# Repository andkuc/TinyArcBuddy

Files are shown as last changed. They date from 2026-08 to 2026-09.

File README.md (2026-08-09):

# Tiny Arc Buddy: Embedded STEM Education Platform

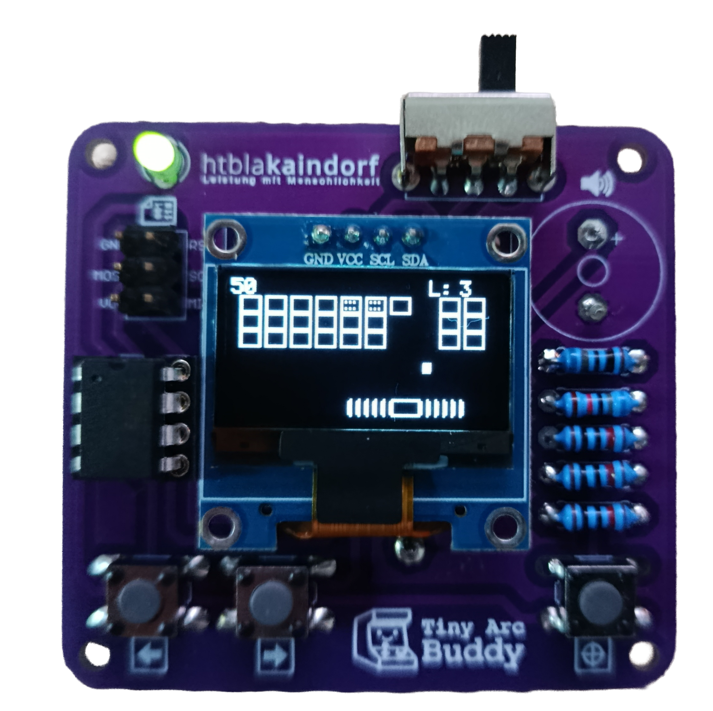
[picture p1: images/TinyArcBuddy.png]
Tiny Arc Buddy


An open-source, ATtiny85-based handheld console designed as a dual-purpose platform: a low-level embedded engineering reference and a hands-on STEM educational tool. It is based on the ATtiny85 Tiny Arcade Console by lonesoulsurfer (https://www.instructables.com/Tiny-Arcade-Game-Attiny85).

Developed for STEM workshops, this project aims to demystify hardware assembly and firmware development for 8th-grade middle school students.

---

## 🧠 Pedagogical Approach

The Tiny Arc Buddy is engineered to provide a frictionless, high-impact introduction to STEM for young students without requiring prior programming or electronics experience.

* **Peer-to-Peer Mentoring:** The workshop utilizes a tiered mentoring model. Middle school students act as "Lead Engineers" executing the hands-on work, while older HTL students serve as "Senior Advisors," fostering a collaborative, non-intimidating learning environment.
* **Tangible Milestones:** Hardware assembly is gamified into structural "Levels" (low-profile to high-profile components). This prevents cognitive overload and provides continuous positive reinforcement.
* **Immediate Feedback Loop:** The firmware is structured with a dedicated `ZONE 1: APP SETTINGS`. Students modify straightforward C++ macros (e.g., `#define OWNER_NAME "ANNA"`) and immediately see their changes compiled and rendered on the OLED. This bridges the abstract code-to-hardware gap without bogging them down in syntax errors.
* **Curriculum Alignment:** The software payloads (such as the Affine Linear Function Explorer) directly correlate with the Austrian 8th-grade mathematics and physics curricula, demonstrating the practical application of theoretical school concepts.

---

## ⚡ Hardware Architecture

| **Front Board Layout** | **Schematic Diagram** |
| :---: | :---: |
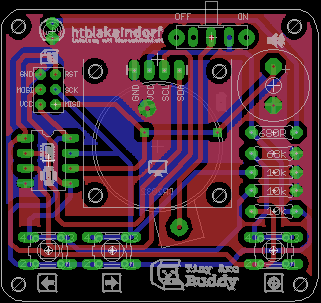
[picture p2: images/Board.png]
Board Layout
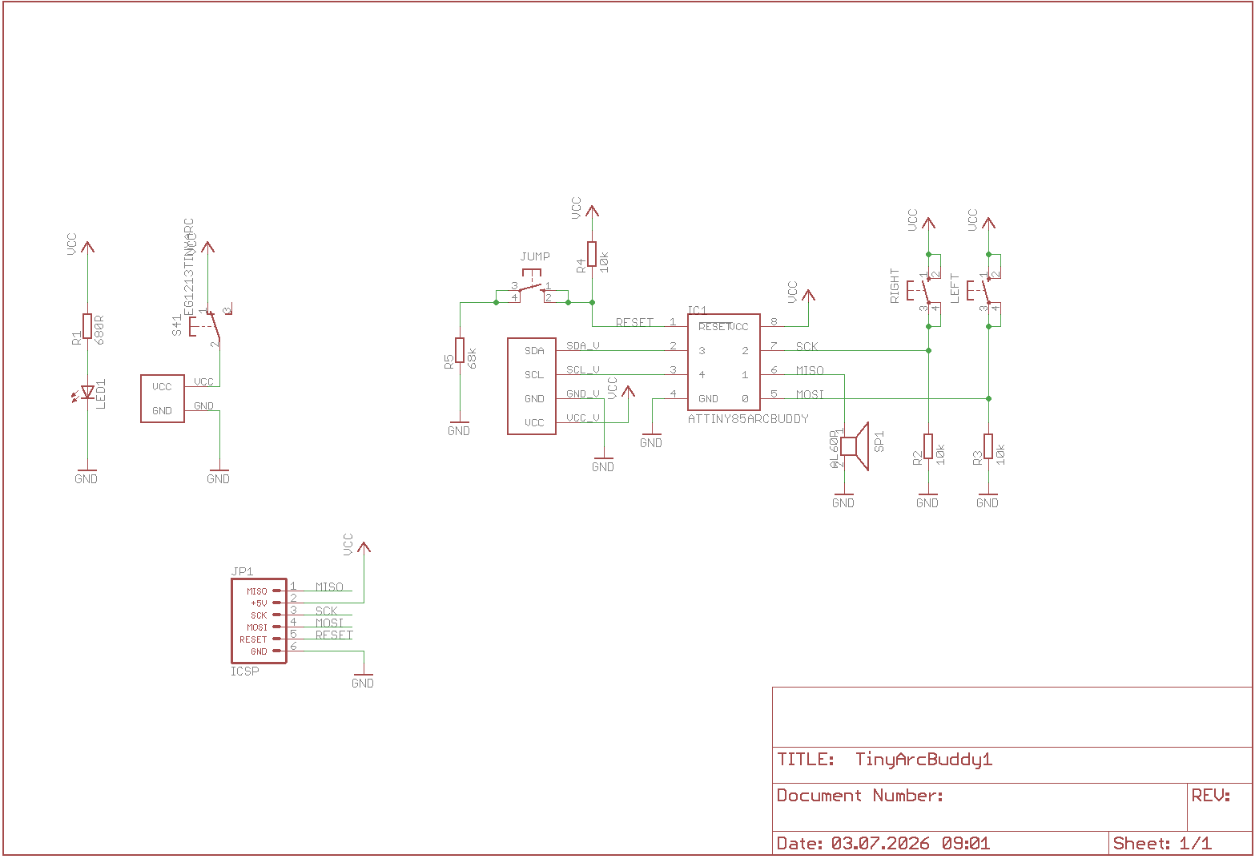
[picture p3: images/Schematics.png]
Circuit Schematic
|  |  |

The hardware is designed around strict BOM constraints, prioritizing low cost, through-hole technology (THT) for beginner soldering, and extreme power efficiency.

* **MCU:** Microchip ATtiny85-20PU (8 KB Flash, 512 Bytes SRAM).
* **Clock:** 8 MHz Internal Oscillator (Fuses must be set; factory 1 MHz will fail I2C timings).
* **Display:** 0.96" I²C SSD1306 Monochrome OLED ($128 \times 64$).
* **Inputs:** * `BTN_LEFT` (PB0) - Direct digital read with internal pull-up.
  * `BTN_RIGHT` (PB2) - Direct digital read with internal pull-up.
  * `BTN_FIRE` (PB5 / ADC0) - Multiplexed via voltage divider (Reset pin constraint).
* **Audio:** Passive Piezo Buzzer driven by PB1.
* **Power:** 3V CR2032 Coin Cell with an SS12F23 slider switch.

> ⚠️ **Hardware Errata / Assembly Note:** > The Piezo Buzzer is routed to PB1 (MISO). Soldering the buzzer *prior* to initial ISP flashing creates signal interference, causing firmware upload failures. The buzzer must be mounted as the final assembly step.

---

## 📑 Bill of Materials (BOM)

| Qty | Component | Designator / Notes |
| :--- | :--- | :--- |
| **1** | Custom PCB | K-Comp / Tiny Arc Buddy revision board |
| **1** | ATtiny85-20PU | Microcontroller (DIP-8 package) |
| **1** | DIL-8 Socket | IC Socket for ATtiny85 |
| **1** | SSD1306 OLED Display | 0.96" I²C Monochrome (128x64) |
| **3** | Resistor 10 kΩ (1%) | Pull-up & voltage divider network |
| **1** | Resistor 68 kΩ (1%) | Battery / Reset line resistor |
| **1** | Resistor 680 Ω (1%) | LED current limiting resistor |
| **3** | Tactile Push Buttons | 6x6 mm Push Buttons (`LEFT`, `RIGHT`, `FIRE`) |
| **1** | Slider Switch | SS12F23 Power Switch |
| **1** | LED 2 mA | Power Indicator Light |
| **1** | CR2032 Battery Holder | **Mount on BOTTOM side of PCB!** |
| **1** | CR2032 3V Battery | Coin Cell Power Source |
| **1** | Passive Piezo Buzzer | **Solder ONLY AFTER programming!** |
| **Tool**| USBasp Programmer | Used for flashing ATtiny85 via DIP-8 socket |

---

## ⚙️ Software Engineering & Memory Optimization

Standard graphics libraries (like Adafruit_SSD1306) require a 1 KB screen buffer, which exceeds the ATtiny85's 512-byte SRAM. The Tiny Arc Buddy firmware bypasses this entirely using custom optimization techniques:

* **Bufferless I²C Rasterization:** The OLED is driven by a custom bit-banged I²C engine (`i2c_start()`, `i2c_write()`). Graphics and text are calculated and pushed to the display pages in real-time, line-by-line, requiring $O(1)$ RAM.
* **Flicker-Free Rendering:** Instead of issuing `oled_clear()` commands, the UI engine employs targeted line-erasure (`clearRestOfLine()`) and fixed-width space padding. This completely eliminates visual artifacts and ghosting during high-frequency loop cycles.
* **Fixed-Point Arithmetic:** To avoid the massive Flash overhead (~1.5 KB) of importing `<math.h>` and utilizing software Floating Point Units (FPU), all physics and geometry calculators use scaled integer math (e.g., storing `3.14` as `314`).
* **PROGMEM Aggregation:** All UI strings, chemical databases, and custom 5x7 compressed hexadecimal font arrays are strictly forced into Flash memory using `pgm_read_byte()` and `pgm_read_word()`.

---

## 📜 Copyright & Licensing

The **Tiny Arc Buddy** is an open educational project developed by Andreas Kucher. To ensure maximum freedom for educators, students, and makers, this repository uses three distinct open-source licenses tailored to different types of content:

### 💻 Software: MIT License
All firmware and source code (`.ino`, `.cpp`, `.h` files) within this repository are released under the **MIT License**.
*Copyright (c) 2026 Andreas Kucher*

You are free to use, copy, modify, merge, publish, distribute, sublicense, and/or sell copies of the software, provided that the original copyright notice and permission notice are included in all copies or substantial portions of the software.

### 🛠️ Hardware: CERN-OHL-P
All hardware design files, including schematics, PCB layouts, and Gerber files, are licensed under the **CERN Open Hardware Licence Version 2 - Permissive (CERN-OHL-P)**. 
You are free to manufacture, modify, and distribute the physical hardware, provided proper attribution is given to the original designers.

### 📖 Documentation: CC BY 4.0
All educational materials, tutorials, and assembly guides (including the *Developer's Handbook*) are licensed under **Creative Commons Attribution 4.0 International (CC BY 4.0)**. 
You are free to share, translate, and adapt the material for any purpose—even commercially—as long as you give appropriate credit to Andreas Kucher.

---

## 🗂️ Repository Structure

```text
.
├── images/
│   ├── Board.png               # PCB component placement & layout render
│   ├── Schematics.png          # Full electronic circuit schematic
├── hardware/
│   ├── TinyArcBuddy.brd        # PCB component placement & layout render
│   ├── TinyArcBuddy1.sch       # Full electronic circuit schematic
│   └── TinyArcBuddy.zip        # Gerber files for PCB manufacturing
├── software/
│   ├── BrickBreaker/           # Brick Breaker Clone
│   ├── LinearFunctions/        # Affine Linear Function Plotter (y = k*x + d)
│   ├── MINTTool/               # SI-Unit aware Math/Physics Engine
│   ├── PeriodicTable/          # 118-Element Relational Database
│   ├── SpaceInvaders/               # Space Invaders
│   ├── TetrisArcade/           # PRNG-driven ATtiny85 Tetris

├── docs/
│   ├── DevelopersGuide.pdf     # Workshop Guide (Student/Tutor Facing)
│   ├── AssortmentBox.pdf       # Kit BOM and assembly order (labels for an assortment box)
│   └── SetupGuide.docx         # Toolchain & driver setup
└── README.md

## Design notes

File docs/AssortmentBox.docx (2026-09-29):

2 | 3 pcs Resistor 10k 1% | 3 | 1 pc Resistor 68k 1% | 4 | 1 pc Resistor 680R 1%
5 | 3 pcs Button | 6 | 1 pc DIL-8 Socket | 7 | 1 pc CR3202 Battery Holder

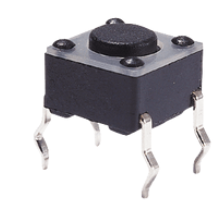
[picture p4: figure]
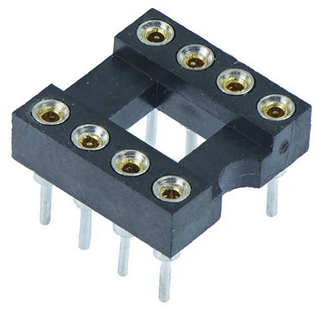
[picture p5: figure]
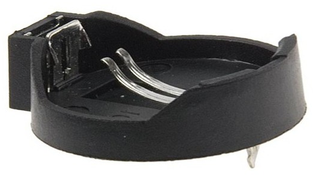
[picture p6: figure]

| | | | MOUNT ON BOTTOM SIDE!
8 | 1 pc SSD1306 I²C OLED 0.96“ | 9 | 1 pc LED 2mA | 10 | 1 pc Slider Switch SS12F23

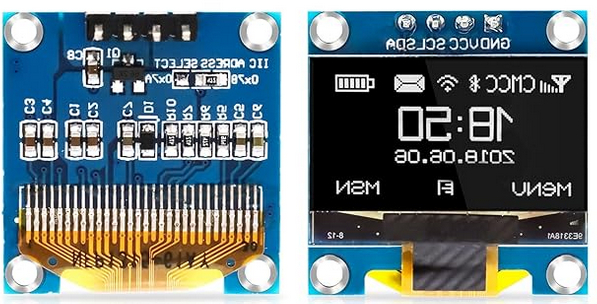
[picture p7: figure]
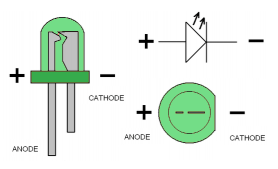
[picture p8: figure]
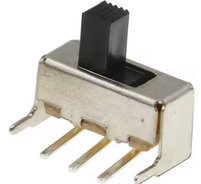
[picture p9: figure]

11 | 1 pc ATTINY85 | TOOL Programmer USBasp | | 12 | 1 pc 3V Battery C2032

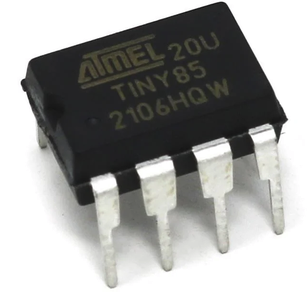
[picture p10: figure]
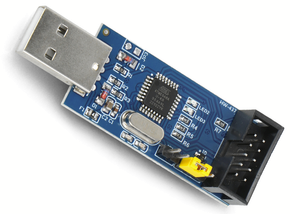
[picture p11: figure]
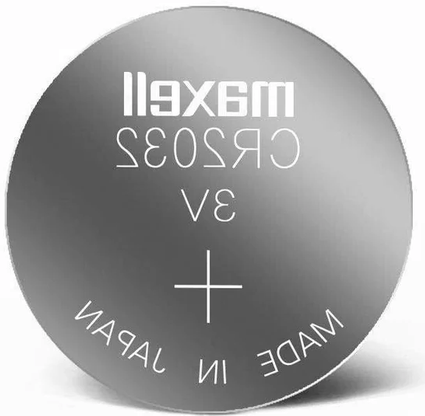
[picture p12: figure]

13 | 1 pc Passive Buzzer | Material Solder | | 1 | 1 pc Tiny Arc Buddy PCB

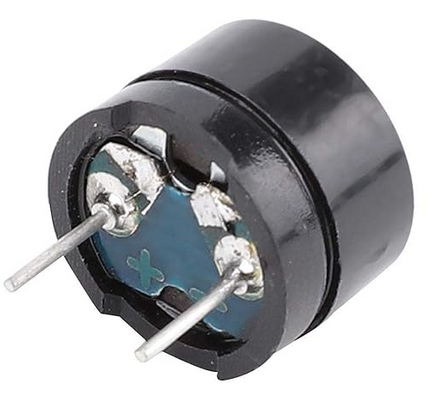
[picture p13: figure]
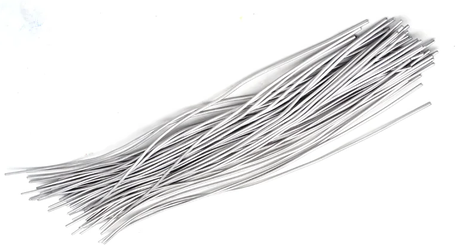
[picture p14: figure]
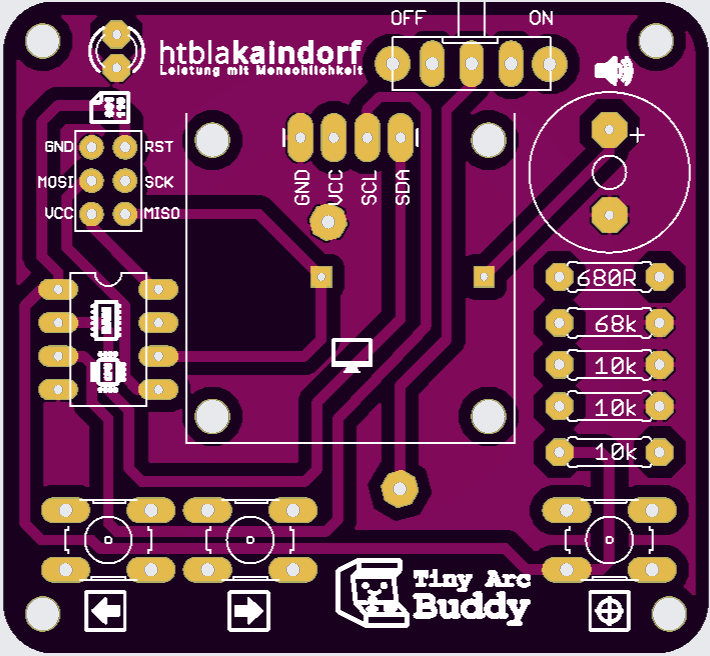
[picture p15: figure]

MOUNT AFTER PROGRAMMING!

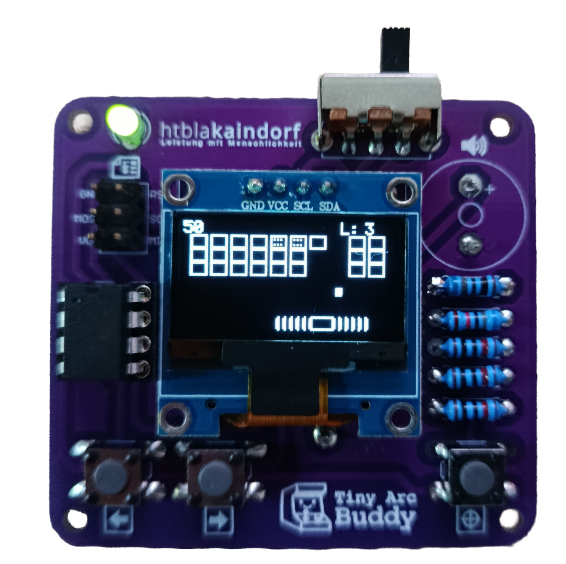
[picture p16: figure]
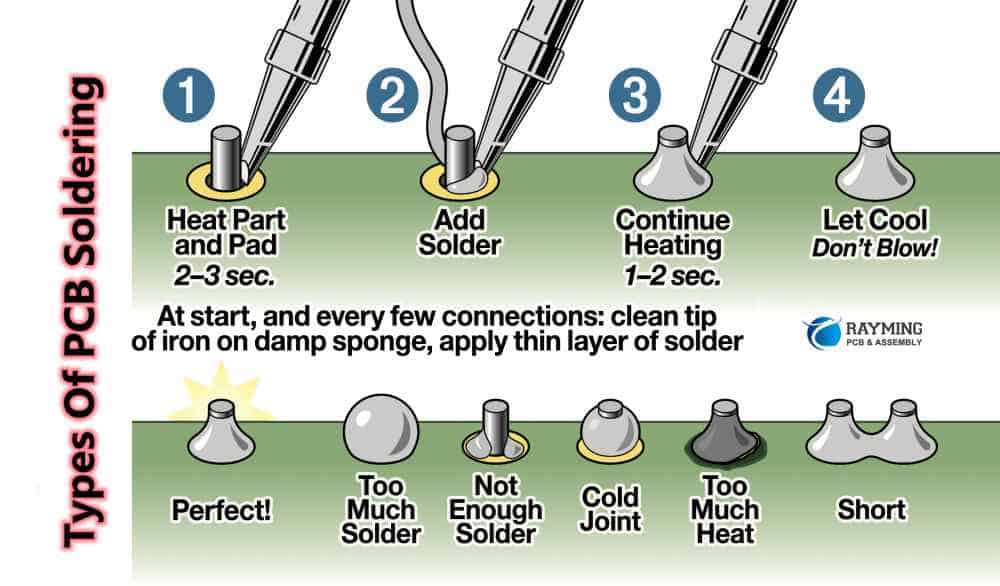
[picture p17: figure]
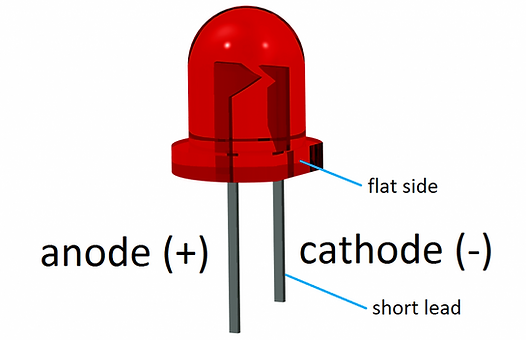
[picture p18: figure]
Wiring LED's to Arduino | The Sim
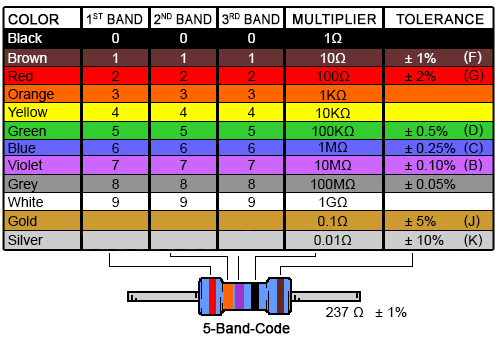
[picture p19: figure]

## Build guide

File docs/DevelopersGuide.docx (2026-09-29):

# 🎮 Tiny Arc Buddy - Entwicklerhandbuch

Teil 1: Was ist der Tiny Arc Buddy?

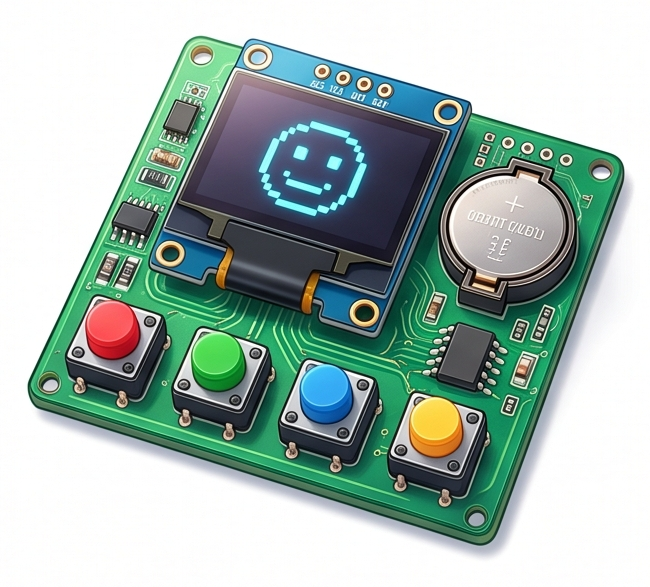
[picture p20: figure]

Willkommen in der Welt der Mikroelektronik! Der Tiny Arc Buddy ist dein eigener kleiner Taschencomputer. Obwohl er nicht viel größer als eine Streichholzschachtel ist, steckt in ihm alles, was auch ein Computer hat: ein Gehirn, ein Gedächtnis, ein Bildschirm, Tasten und ein Lautsprecher! Bevor du deinen eigenen Tiny Arc Buddy selbst aufbaust, sehen wir uns an, aus welchen Bausteinen dein Computer besteht:

🧠 1. Das Gehirn: Der Mikrocontroller (ATtiny85)

Das wichtigste Bauteil ist der kleine schwarze Chip mit den 8 Silberbeinchen. Er heißt ATtiny85.

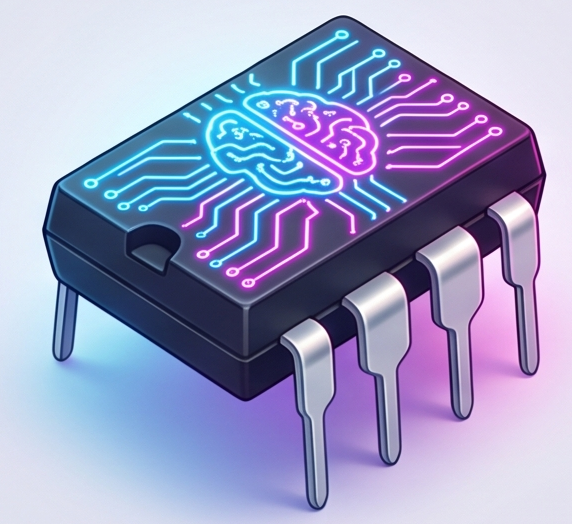
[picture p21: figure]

- Was er macht: Er ist das Gehirn des Computers und führt Programmcode Zeile für Zeile aus.
- Wie schnell er ist: Sein Herz schlägt mit 8 Megahertz. Das bedeutet, er erledigt 8 Millionen Rechenschritte in einer einzigen Sekunde.

🎒 2. Das Gedächtnis: Der Speicher

Dein Tiny Arc Buddy hat zwei verschiedene Arten von Gedächtnis:

- Das Langzeitgedächtnis (Flash-Speicher – 8 Kilobyte): Hier wird dein Programm (der Code) gespeichert. Selbst wenn du die Batterie herausnimmst, vergisst der Chip den Code nicht.
  - Vergleich: Ein Foto ist tausendmal größer, aber weil wir effizient programmieren, passt ein ganzes Mathe-Werkzeug oder Spiel problemlos hinein!
- Das Kurzzeitgedächtnis (SRAM – 512 Byte): Hier merkt sich der Chip Dinge, die sich während des Betriebs ständig ändern – zum Beispiel, welchen Menüpunkt du gerade ausgewählt. Wenn du den Computer ausschaltest, wird dieses Gedächtnis gelöscht.

🖥️ 3. Das Gesicht: Das OLED-Display

Damit du sehen kannst, was dein Computer berechnet, hat er einen kleinen Bildschirm.

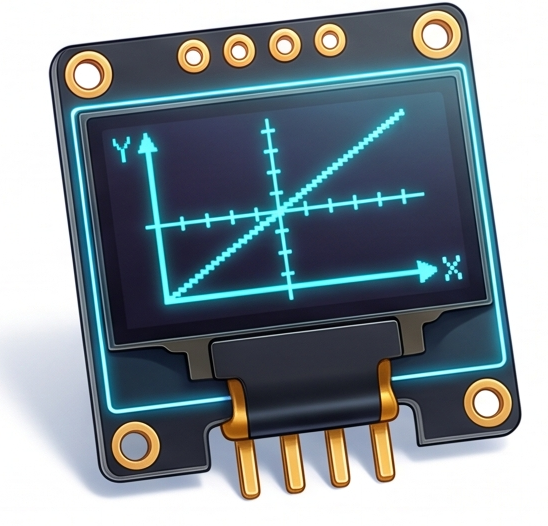
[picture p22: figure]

- Wie es funktioniert: Das Display besteht aus einem Gitter von 128 Pixeln in der Breite und 64 Pixeln in der Höhe (insgesamt 8.192 Lichtpunkte).
- Der ATtiny85 schaltet einzelne Lichtpunkte gezielt EIN oder AUS, um Buchstaben, Zahlen, Koordinatenachsen oder Spielfiguren zu zeichnen.

🕹️ 4. Die Sinne: Tasten, Licht & Ton

- Die Taster (Buttons): Wenn du eine Taste drückst, schließt du einen kleinen Stromkreis. Der ATtiny85 merkt das sofort und reagiert darauf.
- Der Schiebeschalter & die Batterie (CR2032): Die Knopfzelle gibt deinen Bauteilen die nötige Energie (3 Volt). Mit dem Schalter kannst du den Stromfluss starten.
- Der Buzzer (Lautsprecher): Wenn der Prozessor den Strom ganz schnell an- und ausschaltet, fängt eine Membran im Buzzer an zu vibrieren und erzeugt Töne!
- Die LED: Ein kleines Lämpchen, das leuchtet, sobald Strom fließt.

Teil 2: Willkommen im Lab!

Heute spielst du nicht nur ein Spiel – du baust die Konsole selbst! Du wirst löten, deinen eigenen Namen in den Computer-Code schreiben und den Tiny Arc Buddy zum Leben erwecken!

🤝 Lerne dein Team kennen

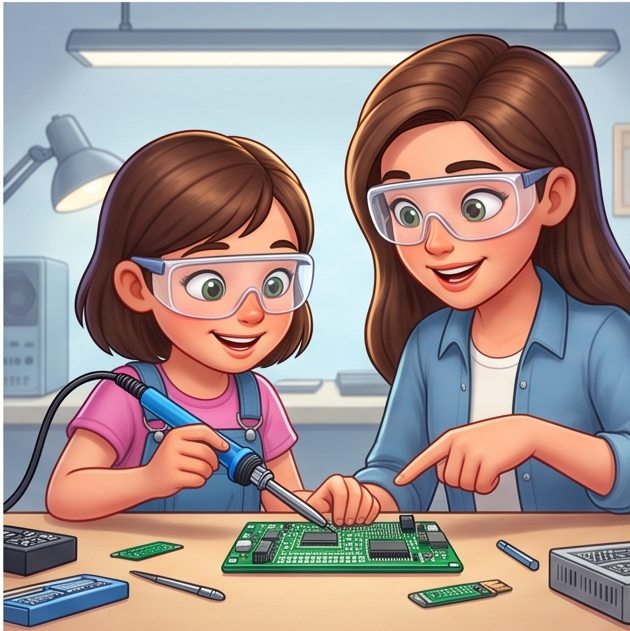
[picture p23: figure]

- Du bist die Chef-Ingenieurin (Lead Engineer). Du hältst die Werkzeuge, lötest die Bauteile und bearbeitest den Computer-Code.
- Deine HTL-Tutorin ist dein Senior Advisor (Berater). Sie ist hier, um dich zu begleiten und dir zu helfen. Wenn du feststeckst, frag sie einfach!

🛑 Sicherheit geht vor (Die 3 Goldenen Regeln)

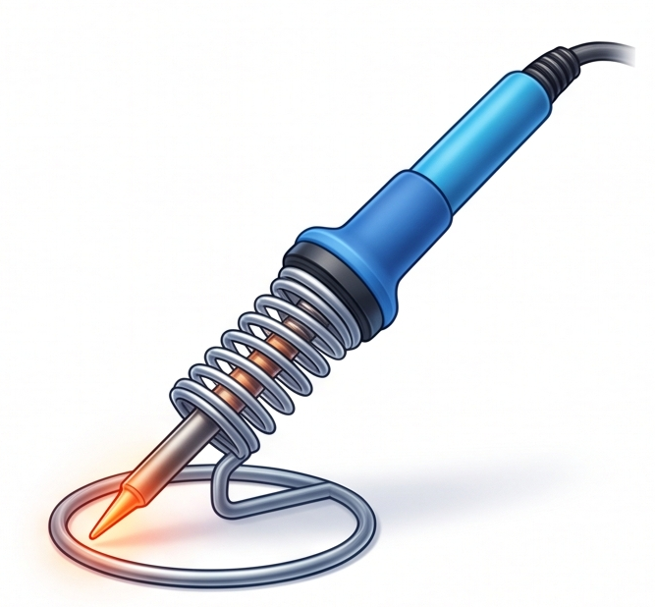
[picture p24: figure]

- Das heiße Ende: Ein Lötkolben wird 330°C heiß. Halte ihn nur am Gummigriff.
- Der Ständer: Lege den Lötkolben immer zurück in den Metallständer.
- Händewaschen: Lötzinn enthält Metalle, die zwar sicher, aber schmutzig sind. Wasch dir nach dem Workshop gründlich die Hände!

Teil 3: Hardware-Montage (Die Löt-Phase)

Es ist Zeit, deinen Tiny Arc Buddy aufzubauen. Alle Bauteile sind in einer Sortimentsbox geordnet.

🛠️ Benötigte Werkzeuge

- Lötkolben & Lötzinn
- Seitenschneider (um die langen Beinchen der Bauteile abzuzwicken)
- Ein leere Tiny Arc Buddy Platine

💡 Wie man wie ein Profi lötet

1. Berühre mit der Spitze des Lötkolbens gleichzeitig den Metallring auf der Platine UND das Beinchen des Bauteils. Erhitze beides für 1–2 Sekunden.
2. Schiebe ein winziges Stück Lötzinn in die heiße Stelle. Es schmilzt sofort wie flüssiges Silber!
3. Zieh zuerst das Lötzinn weg, dann den Lötkolben. Lass es 2 Sekunden abkühlen. Fertig!

🟪Die Assemblierung

- [ ] Widerstände: Finde die 10k, 68k und 680R Widerstände. Biege die Beinchen, stecke sie durch die passenden Löcher und löte sie fest.

💡 Tutor-Tipp: Erkläre kurz, dass Widerstände keine "falsche" Richtung haben.

- [ ] Drucktaster (3x): Stecke die drei Buttons (Taster) ein und löte die Beinchen fest.
- [ ] DIL-8 Sockel: Das ist das "Bett", in dem der ATtiny85 Chip eingesteckt wird.

🛑 Tutor-Tipp: Schau genau auf die Kerbe (die kleine halbkreisförmige Aussparung) an einem Ende des Sockels. Sie muss genau mit der Zeichnung auf der Platine übereinstimmen!

- [ ] CR2032 Batteriehalter: Drehe die Platine um! Der Batteriehalter MUSS auf der Unterseite der Platine festgelötet werden.
- [ ] Das OLED-Display: Stecke die 4 Pins oben in die Platine und löte sie schön gerade fest.
- [ ] Die LED: Dieses Licht zeigt an, ob die Konsole eingeschaltet ist.

🛑 Tutor-Tipp: Das lange Bein kommt in das Loch mit dem Pluszeichen (+).

- [ ] Schiebeschalter: Das ist dein Ein-/Ausschalter. Löte ihn vorsichtig fest.
- [ ] Der ATTiny85 Prozessor: Dein Tutor hilft dir beim Einsetzen!

🚨 STOPP! DIE BUZZER-WARNUNG 🚨

Den runden Buzzer (Lautsprecher) noch NICHT einlöten! Der Buzzer nutzt dieselben Leitungen, die wir brauchen, um den Prozessor zu programmieren. Wir löten den Buzzer erst in Teil 5 ein, nachdem wir mit dem Programmieren fertig sind.

Teil 4: Software Engineering (Die Programmier-Phase)

💻 Chef-Ingenieurin: Den Code anpassen! (Dein Tutor erledigt diesen Teil mit dir!)

Du bist jetzt bereit, deinen Code zu schreiben!

- [ ] Mach es zu deinem: Scrolle im Code nach unten zur ZONE 1. Finde die Zeile mit #define OWNER_NAME. Ändere den Namen innerhalb der Anführungszeichen in deinen eigenen Namen!
- [ ] Tuning: Finde die Zeilen für das Datum (BUILD_DATE) oder die Einstellungen des Programms. Stell alles so ein, wie es dir gefällt!
- [ ] Verbindung zur Programmiergerät: Nimm deinen Tiny Arc Buddy und verbinde ihn mit dem USBasp Programmer.
- [ ] Hochladen: Klicke oben im Menü "Sketch" auf "Upload". Schau zu, wie dein Code in den Chip transferiert wird!

Teil 5: Endmontage & Test

- [ ] Der letzte Lötpunkt: Jetzt, da der Chip programmiert ist, kannst du endlich den runden Passiven Buzzer auf die Vorderseite deiner Platine löten!
- [ ] Einschalten: Schiebe die CR2032 Knopfzelle (Batterie) in die Halterung auf der Rückseite. Die Schrift der Batterie zeigt nach oben.
- [ ] Mission erfüllt: Schalte den Power-Schalter auf ON. Wenn das Tiny Arc Buddy Logo und dein Name auf dem Bildschirm erscheinen, hast du erfolgreich deinen eigenen Taschen-Computer gebaut!

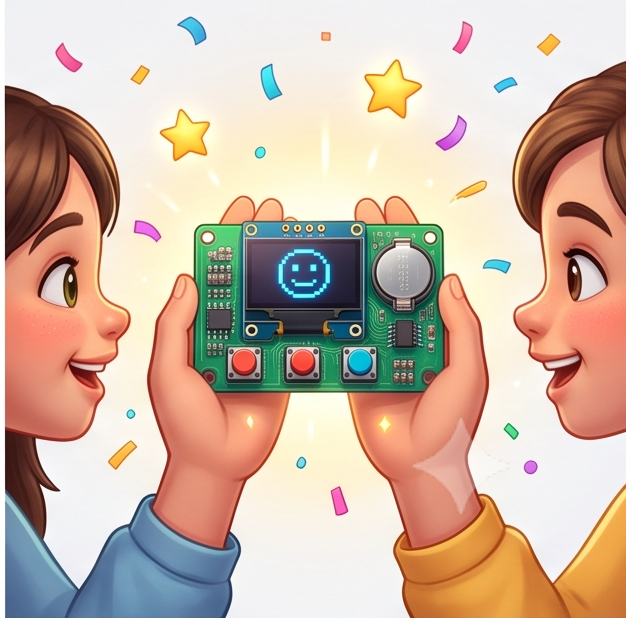
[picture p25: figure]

Herzlichen Glückwunsch, Chef-Ingenieurin! 🎉

Seite | 1 Andreas Kucher

Tiny Arc Buddy – Entwicklerhandbuch

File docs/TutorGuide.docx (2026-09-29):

# 🎮 Tiny Arc Buddy – Tutor Guide

INFORMATIONEN FÜR TUTOREN | INFORMATIONEN FÜR TUTOREN | INFORMATIONEN FÜR TUTOREN TUTOREN

🧑‍💻 TUTOR-VORBEREITUNG Die Chef-Ingenieurinnen, macht 5 Minuten Pause, während euer Tutor alles einrichtet!

Schritt 1: USBasp Treiber installieren

- Zadig (https://zadig.akeo.ie) herunterladen und installieren.
- USBasp Programmer an den PC anstecken.
- USBasp und libusbK (vx.x.x.x) auswählen.
- Reinstall WICD Driver auswählen. (Dies dauert möglicherweise eine Weile.)

Schritt 2: Arduino IDE einrichten

- Arduino IDE öffnen. Gehe zu File -> Preferences.
- Füge diesen Link bei Additional Boards-Manager-URLs ein: http://drazzy.com/package_drazzy.com_index.json
- Gehe zu Tools -> Board -> Boards-Manger. Suche nach ATTinyCore (Spence Konde) und installiere es.

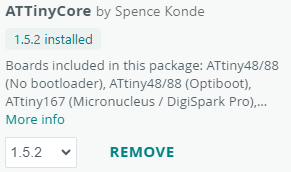
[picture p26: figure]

Schritt 3: Projektdateien laden

- Öffne unser offizielles GitHub-Repository (https://github.com/andkuc/TinyArcBuddy).
- Lade die .zip Datei herunter, entpacke sie und öffne eine der .ino Dateien in der Arduino IDE.

Schritt 4: Board-Einstellungen konfigurieren Gehe ins Menü Tools und stelle diese Parameter ein:

- Board: ATtiny25/45/85 (No bootloader)
- Chip: ATtiny85
- Clock Source: 8 MHz (Internal)
- Programmer: USBasp

Schritt 5: Bootloader brennen (Fuses setzen)

- Wichtiger Schritt: Auch wenn wir keinen echten Bootloader nutzen, müsst ihr einmal auf Tools -> Burn Bootloader klicken. Das ändert den werkseitigen 1MHz-Takt des Chips auf den 8MHz-Takt, den wir für das Display brauchen!

Seite | 1 Andreas Kucher

Tiny Arc Buddy – Tutor Guide

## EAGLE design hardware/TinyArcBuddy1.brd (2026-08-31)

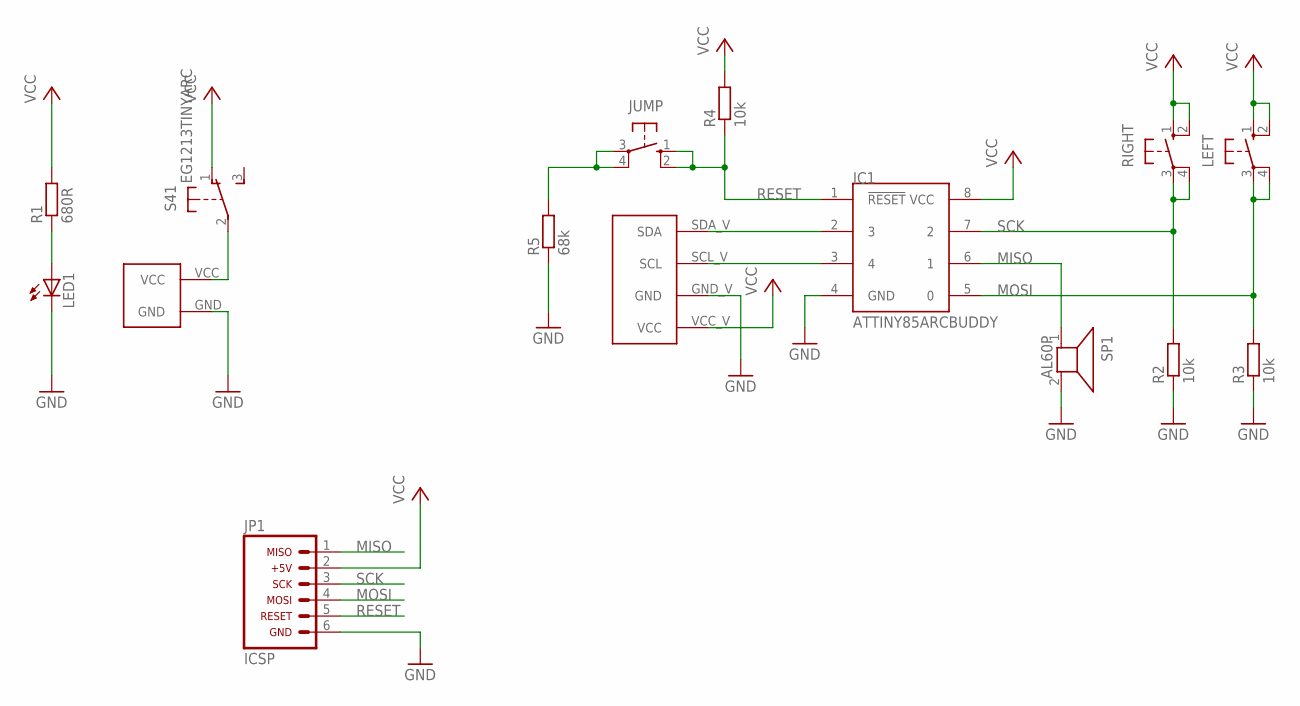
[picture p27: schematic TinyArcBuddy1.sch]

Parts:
IC1: ATTINY85ARCBUDDY; DIL08
JP1: ARDUINO_CONN-ICSPTINYARC; CONN-2X03_TINYARC
JUMP: 10-XX; B3F-10XX
LED1: LED3MM
LEFT: 10-XX; B3F-10XX
R1: 680R; 0207/10
R2, R3, R4: 10k; 0207/10
R5: 68k; 0207/10
RIGHT: 10-XX; B3F-10XX
S4: EG1213TINYARC; EG1213_TINYARC
SP1: AL60P
U$1: I2C_OLEDTINYARC; I2C_OLED_PACKAGE_TINYARC
U$2: CR2032; CR2032-20MM

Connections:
GND: IC1.4 (GND), JP1.6, LED1.K (C), R2.1, R3.1, R5.1, SP1.2, U$1.GND_V (GND), U$2.GND
MISO: IC1.6 (1), JP1.1, SP1.1
MOSI: IC1.5 (0), JP1.4, LEFT.3, LEFT.4 (P1), R3.2
unnamed: IC1.3 (4), U$1.SCL_V (SCL)
unnamed: IC1.2 (3), U$1.SDA_V (SDA)
unnamed: S4.2, U$2.VCC
unnamed: LED1.A, R1.1
unnamed: JUMP.3, JUMP.4 (P1), R5.2
RESET: IC1.1 (!RESET), JP1.5, JUMP.1 (S), JUMP.2 (S1), R4.1
SCK: IC1.7 (2), JP1.3, R2.2, RIGHT.3, RIGHT.4 (P1)
VCC: IC1.8 (VCC), JP1.2, LEFT.1 (S), LEFT.2 (S1), R1.2, R4.2, RIGHT.1 (S), RIGHT.2 (S1), S4.1 (O), U$1.VCC_V (VCC)

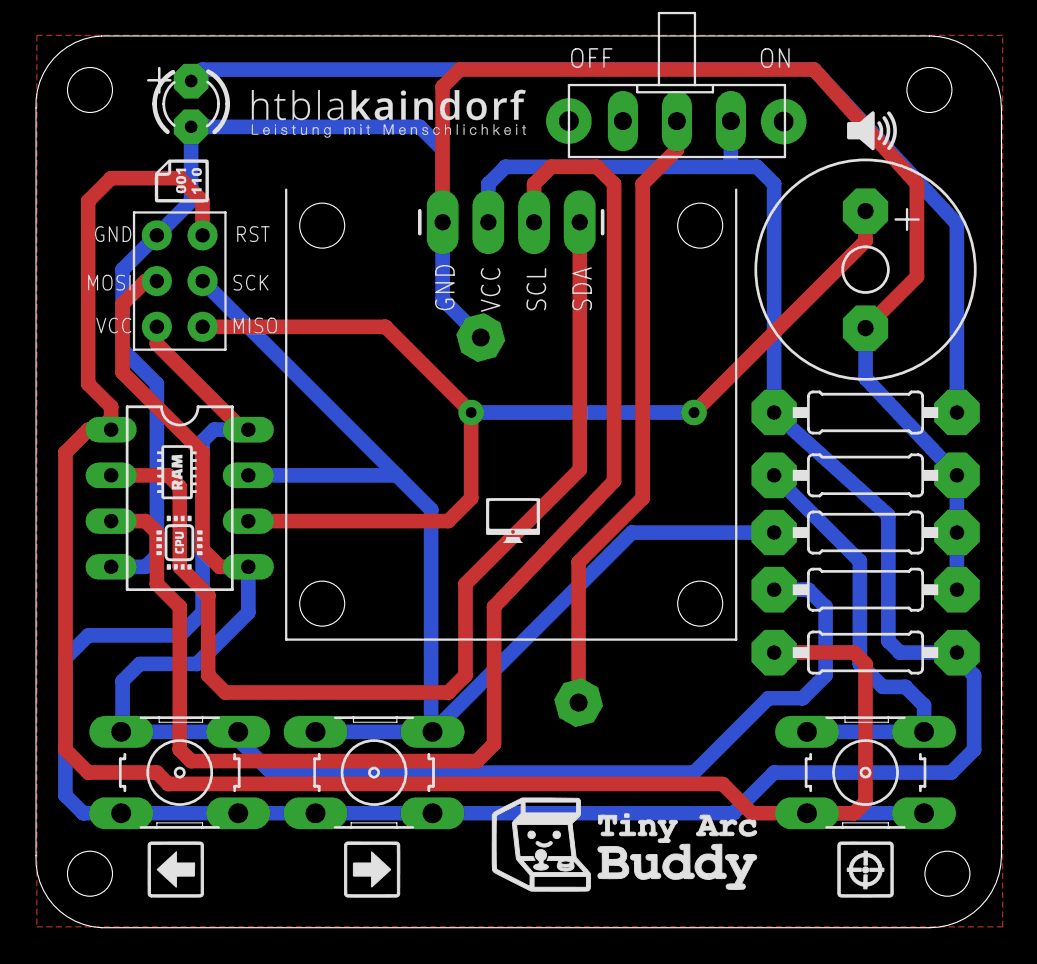
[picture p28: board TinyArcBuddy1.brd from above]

Board: 2 copper layers, 53.6 x 49.5 mm, 15 parts (1 on the bottom side), 11 nets.

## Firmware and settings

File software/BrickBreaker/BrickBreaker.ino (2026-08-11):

/*
 * =========================================================================================
 * TINY ARC BUDDY - EDUCATIONAL EMBEDDED PLATFORM
 * =========================================================================================
 * * Copyright (c) 2026 Andreas Kucher
 * * Permission is hereby granted, free of charge, to any person obtaining a copy
 * of this software and associated documentation files (the "Software"), to deal
 * in the Software without restriction, including without limitation the rights
 * to use, copy, modify, merge, publish, distribute, sublicense, and/or sell
 * copies of the Software, and to permit persons to whom the Software is
 * furnished to do so, subject to the following conditions:
 * * The above copyright notice and this permission notice shall be included in all
 * copies or substantial portions of the Software.
 * * THE SOFTWARE IS PROVIDED "AS IS", WITHOUT WARRANTY OF ANY KIND, EXPRESS OR
 * IMPLIED, INCLUDING BUT NOT LIMITED TO THE WARRANTIES OF MERCHANTABILITY,
 * FITNESS FOR A PARTICULAR PURPOSE AND NONINFRINGEMENT. IN NO EVENT SHALL THE
 * AUTHORS OR COPYRIGHT HOLDERS BE LIABLE FOR ANY CLAIM, DAMAGES OR OTHER
 * LIABILITY, WHETHER IN AN ACTION OF CONTRACT, TORT OR OTHERWISE, ARISING FROM,
 * OUT OF OR IN CONNECTION WITH THE SOFTWARE OR THE USE OR OTHER DEALINGS IN THE
 * SOFTWARE.
 * * -----------------------------------------------------------------------------------------
 * ACKNOWLEDGMENTS & DISCLAIMER
 * -----------------------------------------------------------------------------------------
 * This project was designed for STEM education workshops.
 * * Core hardware architecture derived from:
 * "Tiny Arcade Game (ATtiny85)" - Instructables
 * * Hardware support via:
 * ATTinyCore by Spence Konde (https://github.com/SpenceKonde/ATTinyCore)
 * * Disclaimer: The software payloads in this repository were heavily optimized 
 * for ATtiny85 SRAM/Flash constraints with the assistance of AI (Google Gemini). 
 * They have not undergone exhaustive edge-case testing. Use for educational purposes.
 * =========================================================================================
 */

/*
 * ==============================================================================
 * TINY ARC BUDDY - BRICK BREAKER EDITION (PERFORMANCE UPDATE)
 * ==============================================================================
 */

#include <avr/io.h>
#include <util/delay.h>
#include <EEPROM.h>

#include "font.h"     
#include "graphics.h" 
#include "levels.h"

// ==============================================================================
// ZONE 1: THE GAME RULES (Modify These!)
// ==============================================================================

#define PLAYER_NAME "ANNA"           
#define BUILD_DATE "25.04.2026"      

#define STARTING_LIVES 3             
#define BRICK_POINTS 10              
#define PADDLE_SPEED 4               // Increased speed for snappy controls!

// --- Global Game Pacing ---
#define GAME_FPS 30                  
#define BASE_BALL_SPEED 8            

// --- Music Studio ---
const int levelUpMelody[] PROGMEM = { 440, 554, 659, 880 }; 
const int levelUpTempo[]  PROGMEM = { 100, 100, 100, 300 };

const int gameOverMelody[] PROGMEM = { 300, 250, 200, 150 };
const int gameOverTempo[]  PROGMEM = { 300, 300, 300, 600 };

// ==============================================================================
// ZONE 2: THE ENGINE (Danger Zone!)
// ==============================================================================

// RESTORED PROVEN HARDWARE PINS!
#define OLED_SDA PB3  
#define OLED_SCL PB4  
#define BTN_LEFT PB0  
#define BTN_RIGHT PB2 
#define BUZZER PB1    

// --- Game State ---
byte gameState = 0; 
int highScore = 0;
int score = 0;
int lives = STARTING_LIVES;
int level = 1;

byte currentLevel[BRICK_ROWS * BRICK_COLS]; 
int bricksRemaining = 0;

int paddleX = 56; 
int paddleMode = 0;   
int paddleTimer = 0;  

bool modActive = false;
int modX = -1;
int modPage = -1;
int modTick = 0;

// Fixed-Point Physics Engine
int ballX = 640; 
int ballY = 500;
int ballDx = 8;  
int ballDy = -8; 
int oldDrawX = -1;
int oldDrawY = -1;

unsigned long lastFrameTime = 0;

// ------------------------------------------------------------------------------
// I2C BIT-BANGING & OLED DRIVERS 
// ------------------------------------------------------------------------------
void i2c_write(uint8_t data) {
  for (uint8_t i = 0; i < 8; i++) {
    if (data & 0x80) PORTB |= (1 << OLED_SDA); else PORTB &= ~(1 << OLED_SDA);
    PORTB |= (1 << OLED_SCL); PORTB &= ~(1 << OLED_SCL);
    data <<= 1;
  }
  PORTB |= (1 << OLED_SCL); PORTB &= ~(1 << OLED_SCL);
}

void oled_command(uint8_t cmd) {
  PORTB |= (1 << OLED_SCL) | (1 << OLED_SDA);
  PORTB &= ~(1 << OLED_SDA); PORTB &= ~(1 << OLED_SCL);
  i2c_write(0x78); i2c_write(0x00); i2c_write(cmd);
  PORTB &= ~(1 << OLED_SDA);
  PORTB |= (1 << OLED_SCL) | (1 << OLED_SDA);
}

void oled_set_cursor(uint8_t x, uint8_t y) {
  oled_command(0xB0 + y);                 
  oled_command(0x00 + (x & 0x0F));        
  oled_command(0x10 + ((x >> 4) & 0x0F)); 
}

void oled_clear() {
  for (uint8_t y = 0; y < 8; y++) {
    oled_set_cursor(0, y);
    PORTB |= (1 << OLED_SCL) | (1 << OLED_SDA);
    PORTB &= ~(1 << OLED_SDA); PORTB &= ~(1 << OLED_SCL);
    i2c_write(0x78); i2c_write(0x40);
    for (uint8_t x = 0; x < 128; x++) i2c_write(0x00);
    PORTB &= ~(1 << OLED_SDA);
    PORTB |= (1 << OLED_SCL) | (1 << OLED_SDA);
  }
}

// ------------------------------------------------------------------------------
// GRAPHICS & SOUND FUNCTIONS
// ------------------------------------------------------------------------------
void drawChar(uint8_t x, uint8_t page, char c) {
  uint8_t idx = 0;
  bool isSpace = false;
  if (c >= '0' && c <= '9') idx = c - '0' + 1;
  else if (c >= 'A' && c <= 'Z') idx = c - 'A' + 11;
  else if (c == '\'') idx = 37; else if (c == '@') idx = 38;
  else if (c == ':') idx = 39; else if (c == '.') idx = 40;
  else if (c == ' ') { isSpace = true; }
  
  oled_set_cursor(x, page);
  PORTB |= (1 << OLED_SCL) | (1 << OLED_SDA);
  PORTB &= ~(1 << OLED_SDA); PORTB &= ~(1 << OLED_SCL);
  i2c_write(0x78); i2c_write(0x40);
  
  if (isSpace) {
    for(uint8_t i=0; i<6; i++) i2c_write(0x00);
  } else {
    for(uint8_t i=0; i<5; i++) i2c_write(pgm_read_byte(&font5x7[idx * 5 + i]));
    i2c_write(0x00); 
  }
  PORTB &= ~(1 << OLED_SDA); PORTB |= (1 << OLED_SCL) | (1 << OLED_SDA);
}

void drawString(uint8_t x, uint8_t page, const char* str) {
  while (*str) { drawChar(x, page, *str++); x += 6; }
}

void drawInt(uint8_t x, uint8_t page, int val) {
  char str[6]; itoa(val, str, 10); drawString(x, page, str);
}

void drawUI() {
  drawInt(0, 0, score);
  drawString(95, 0, "L:"); drawInt(110, 0, lives);
}

void drawSprite(int x, uint8_t page, const uint8_t* sprite, uint8_t width, bool eraseSides = false) {
  if (x < 0 || x > 127) return; 
  int startX = x;
  if (eraseSides) { if (startX >= 2) startX -= 2; else startX = 0; }
  
  oled_set_cursor(startX, page);
  PORTB |= (1 << OLED_SCL) | (1 << OLED_SDA);
  PORTB &= ~(1 << OLED_SDA); PORTB &= ~(1 << OLED_SCL);
  i2c_write(0x78); i2c_write(0x40);
  
  if (eraseSides) { i2c_write(0); i2c_write(0); }
  if (sprite != NULL) {
    for(uint8_t i=0; i<width; i++) { if (startX + i <= 127) i2c_write(pgm_read_byte(&sprite[i])); }
  } else {
    for(uint8_t i=0; i<width; i++) i2c_write(0x00); 
  }
  if (eraseSides) { i2c_write(0); i2c_write(0); }
  PORTB &= ~(1 << OLED_SDA); PORTB |= (1 << OLED_SCL) | (1 << OLED_SDA);
}

void drawLargeSprite(uint8_t x, uint8_t startPage, const uint8_t* sprite, uint8_t width, uint8_t pages) {
  for (uint8_t p = 0; p < pages; p++) {
    oled_set_cursor(x, startPage + p);
    PORTB |= (1 << OLED_SCL) | (1 << OLED_SDA);
    PORTB &= ~(1 << OLED_SDA); PORTB &= ~(1 << OLED_SCL);
    i2c_write(0x78); i2c_write(0x40);
    for(uint8_t i = 0; i < width; i++) i2c_write(pgm_read_byte(&sprite[(p * width) + i]));
    PORTB &= ~(1 << OLED_SDA); PORTB |= (1 << OLED_SCL) | (1 << OLED_SDA);
  }
}

void renderBall(int x, int y, bool erase) {
  if (x < 0 || x > 124 || y < 0 || y > 60) return;
  uint8_t page1 = y / 8; uint8_t page2 = (y + 3) / 8;
  uint8_t shift1 = y % 8; uint8_t shift2 = 8 - shift1;
  uint8_t mask = 0b00001111; 

  PORTB |= (1 << OLED_SCL) | (1 << OLED_SDA);
  for(uint8_t p = page1; p <= page2; p++) {
      oled_set_cursor(x, p);
      PORTB &= ~(1 << OLED_SDA); PORTB &= ~(1 << OLED_SCL);
      i2c_write(0x78); i2c_write(0x40);
      
      for(uint8_t i=0; i<4; i++) {
          uint8_t col = mask;
          if (p == page1) col <<= shift1; else col >>= shift2;
          if (erase) i2c_write(0); else i2c_write(col);
      }
      PORTB &= ~(1 << OLED_SDA); PORTB |= (1 << OLED_SCL) | (1 << OLED_SDA);
  }
}

void beep(int freq, int duration) {
  int halfPeriod = 1000000L / freq / 2;
  long loops = (long)duration * 1000L / (halfPeriod * 2);
  for (long i=0; i<loops; i++) {
    PORTB |= (1 << BUZZER); delayMicroseconds(halfPeriod);
    PORTB &= ~(1 << BUZZER); delayMicroseconds(halfPeriod);
  }
}

void playCustomSong(const int* notes, const int* durations, int length) {
  for(int i=0; i<length; i++) {
    int note = pgm_read_word(&notes[i]);
    int duration = pgm_read_word(&durations[i]);
    if (note > 0) beep(note, duration); else delay(duration);
    delay(20); 
  }
}

bool readLeft() { return (PINB & (1 << BTN_LEFT)); } 
bool readRight() { return (PINB & (1 << BTN_RIGHT)); } 
bool readFire() {
  ADCSRA |= (1 << ADSC); 
  while (ADCSRA & (1 << ADSC)); 
  return (ADC < 950); 
}

// ------------------------------------------------------------------------------
// GAME LOGIC
// ------------------------------------------------------------------------------
void loadLevel(int lvlNum) {
  oled_clear(); drawUI();
  
  int ptrIdx = (lvlNum - 1) % 10; 
  const uint8_t* lvlPtr = (const uint8_t*)pgm_read_word(&levelData[ptrIdx]);
  
  bricksRemaining = 0; modActive = false; paddleMode = 0;
  
  for (int i = 0; i < (BRICK_ROWS * BRICK_COLS); i++) {
    uint8_t bType = pgm_read_byte(&lvlPtr[i]);
    currentLevel[i] = bType;
    if (bType == 1 || bType == 2 || bType == 4) bricksRemaining++;
    
    int row = i / BRICK_COLS; int col = i % BRICK_COLS;
    if (bType > 0) {
      const uint8_t* bSp = (bType==1)?brick_1 : ((bType==2)?brick_2 : ((bType==3)?brick_3 : brick_4));
      drawSprite(4 + (col * 12), row + 1, bSp, 10, false); 
    }
  }
  
  paddleX = 56;
  ballX = (paddleX + 6) * 10; ballY = 510; 
  ballDx = BASE_BALL_SPEED + (level/2); ballDy = -(BASE_BALL_SPEED + (level/2));
  
  oldDrawX = -1; oldDrawY = -1;
  drawSprite(paddleX, 7, custom_paddle, 16, false);
}

void setup() {
  DDRB |= (1 << OLED_SDA) | (1 << OLED_SCL) | (1 << BUZZER);
  DDRB &= ~((1 << BTN_LEFT) | (1 << BTN_RIGHT));
  PORTB &= ~((1 << BTN_LEFT) | (1 << BTN_RIGHT)); 
  
  ADMUX = 0b00000000;  
  ADCSRA = 0b10000011; 

  oled_command(0xAE); oled_command(0x20); oled_command(0x02); 
  oled_command(0xA1); oled_command(0xC8); 
  oled_command(0x8D); oled_command(0x14); 
  oled_command(0xAF); 
  
  EEPROM.get(0, highScore);
  if (highScore == -1 || highScore > 9999) highScore = 0; 
}

void loop() {
  unsigned long currentMillis = millis();

  // STATE 0: HTL LOGO SPLASH
  if (gameState == 0) {
    oled_clear();
    drawLargeSprite(48, 2, htl_logo, 32, 4); 
    drawString(25, 7, "BRICK BREAKER");
    delay(3000); 
    gameState = 1; 
  }

  // STATE 1: CREDITS & HIGH SCORE
  if (gameState == 1) {
    oled_clear();
    drawString(3, 0, "GIRLS' DAY"); drawString(3, 1, "@ HTL KAINDORF");
    drawString(3, 3, "BUILT BY:"); drawString(60, 3, PLAYER_NAME); 
    drawString(3, 4, "ON "); drawString(25, 4, BUILD_DATE);  
    drawString(3, 6, "HIGH SCORE:"); drawInt(75, 6, highScore);
    
    while(!readFire()) { /* Wait */ }
    beep(1000, 100);
    score = 0; lives = STARTING_LIVES; level = 1;
    gameState = 2; 
  }

  // STATE 2: LEVEL START
  if (gameState == 2) {
    loadLevel(level);
    drawString(40, 4, "READY?");
    delay(1000);
    drawString(40, 4, "      "); 
    lastFrameTime = millis();
    gameState = 3;
  }

  // STATE 3: PLAYING
  if (gameState == 3) {
    if (currentMillis - lastFrameTime < (1000 / GAME_FPS)) return; 
    lastFrameTime = currentMillis;

    // --- Flawless Paddle Movement & Boundary Logic ---
    int pW = (paddleMode == 1) ? 24 : 16;
    
    if (readLeft()) {
      paddleX -= PADDLE_SPEED;
      if (paddleX < 0) paddleX = 0;
    }
    if (readRight()) {
      paddleX += PADDLE_SPEED;
      if (paddleX > 128 - pW) paddleX = 128 - pW; // Prevents "sinking" into the wall!
    }
    
    const uint8_t* pSprite = (paddleMode == 1) ? custom_paddle_wide : custom_paddle;
    drawSprite(paddleX, 7, pSprite, pW, true); 

    // --- Mod Timers ---
    if (paddleMode == 1) {
      paddleTimer--;
      if (paddleTimer <= 0) {
        paddleMode = 0;
        drawSprite(paddleX, 7, NULL, 24, false); 
        beep(500, 50); 
      }
    }

    if (modActive) {
      modTick++;
      if (modTick > 2) {
        modTick = 0;
        drawSprite(modX, modPage, NULL, 8, false); 
        modPage++;
        if (modPage == 7) { 
          if (modX + 8 >= paddleX && modX <= paddleX + pW) { 
            paddleMode = 1; paddleTimer = 300; 
            if (paddleX > 128 - 24) paddleX = 128 - 24; 
            beep(1000, 30); beep(1500, 30);
            drawSprite(paddleX - 4, 7, NULL, 32, false); 
          }
          modActive = false;
        } else if (modPage > 7) {
          modActive = false;
        } else {
          drawSprite(modX, modPage, fx_powerup, 8, false); 
        }
      }
    }

    // --- AABB Physics Engine ---
    ballX += ballDx; ballY += ballDy;
    
    int drawX = ballX / 10; int drawY = ballY / 10;
    int ballRight = drawX + 3; int ballBottom = drawY + 3;

    // Wall Bounces (Shortened beeps prevent audio lag!)
    if (drawX <= 0) { ballDx = abs(ballDx); ballX = 10; beep(600, 3); }
    if (ballRight >= 127) { ballDx = -abs(ballDx); ballX = 1230; beep(600, 3); }
    if (drawY <= 9) { ballDy = abs(ballDy); ballY = 100; beep(600, 3); }

    // Floor (Death)
    if (drawY >= 60) {
      lives--;
      beep(150, 300); delay(500);
      renderBall(oldDrawX, oldDrawY, true); 
      drawUI(); paddleMode = 0; 
      
      if (lives <= 0) gameState = 4;
      else {
        drawSprite(paddleX, 7, NULL, 24, false); 
        paddleX = 56;
        ballX = (paddleX + 6) * 10; ballY = 510; 
        ballDx = BASE_BALL_SPEED + (level/2); ballDy = -(BASE_BALL_SPEED + (level/2));
        oldDrawX = -1; oldDrawY = -1;
        delay(500);
      }
    }

    // Paddle Bounce
    if (ballBottom >= 52 && drawY <= 54 && ballDy > 0) {
      if (ballRight >= paddleX && drawX <= paddleX + pW) {
        ballDy = -ballDy; ballY = 480;
        int hitPos = (drawX + 2) - (paddleX + pW / 2);
        ballDx = hitPos * 1; 
        if (ballDx > 12) ballDx = 12; if (ballDx < -12) ballDx = -12;
        if (ballDx == 0) ballDx = (random(2) == 0) ? 4 : -4; 
        beep(800, 8); // Shortened beep!
      }
    }

    // AABB Brick Bounce
    bool bouncedX = false;
    bool bouncedY = false;

    if (ballBottom >= 8 && drawY <= 39) {
      for (int row = 0; row < BRICK_ROWS; row++) {
        for (int col = 0; col < BRICK_COLS; col++) {
          int idx = row * BRICK_COLS + col;
          uint8_t bType = currentLevel[idx];

          if (bType > 0) {
            int brickLeft = 4 + (col * 12);
            int brickRight = brickLeft + 9;
            int brickTop = 8 + (row * 8);
            int brickBottom = brickTop + 7;

            if (ballRight >= brickLeft && drawX <= brickRight &&
                ballBottom >= brickTop && drawY <= brickBottom) {

                int oldX = (oldDrawX == -1) ? drawX : oldDrawX;
                int oldY = (oldDrawY == -1) ? drawY : oldDrawY;
                
                if (oldX + 3 < brickLeft || oldX > brickRight) {
                  if (!bouncedX) { ballDx = -ballDx; bouncedX = true; }
                }
                if (oldY + 3 < brickTop || oldY > brickBottom) {
                  if (!bouncedY) { ballDy = -ballDy; bouncedY = true; }
                }
                if (!bouncedX && !bouncedY) {
                  ballDx = -ballDx; ballDy = -ballDy;
                  bouncedX = true; bouncedY = true;
                }

                ballX += ballDx; ballY += ballDy;
                drawX = ballX / 10; drawY = ballY / 10;
                
                beep(1500, 8); // Shortened beep!

                if (bType == 1 || bType == 4) {
                  currentLevel[idx] = 0; bricksRemaining--; score += BRICK_POINTS;
                  drawSprite(brickLeft - 2, row + 1, NULL, 14, false); 
                  drawUI();

                  if (bType == 4 && !modActive) {
                    modActive = true; modX = brickLeft + 1; modPage = row + 1; modTick = 0;
                  }
                } else if (bType == 2) {
                  currentLevel[idx] = 1; score += (BRICK_POINTS / 2);
                  drawSprite(brickLeft, row + 1, brick_1, 10, false);
                  drawUI();
                }

                // Repair adjacent bricks
                if (col > 0 && currentLevel[idx - 1] > 0) {
                   uint8_t t = currentLevel[idx - 1];
                   const uint8_t* sp = (t==1)?brick_1 : ((t==2)?brick_2 : ((t==3)?brick_3 : brick_4));
                   drawSprite(4 + ((col-1)*12), row + 1, sp, 10, false);
                }
                if (col < BRICK_COLS - 1 && currentLevel[idx + 1] > 0) {
                   uint8_t t = currentLevel[idx + 1];
                   const uint8_t* sp = (t==1)?brick_1 : ((t==2)?brick_2 : ((t==3)?brick_3 : brick_4));
                   drawSprite(4 + ((col+1)*12), row + 1, sp, 10, false);
                }

                if (bricksRemaining == 0) {
                  playCustomSong(levelUpMelody, levelUpTempo, 4);
                  level++; gameState = 2; return;
                }
            }
          }
        }
      }
    }

    if (gameState == 3) {
      if (oldDrawX != -1) renderBall(oldDrawX, oldDrawY, true); 
      renderBall(drawX, drawY, false); 
      oldDrawX = drawX; oldDrawY = drawY;
    }
  }

  // STATE 4: GAME OVER
  if (gameState == 4) {
    if (score > highScore) { highScore = score; EEPROM.put(0, highScore); }

    oled_clear();
    drawString(35, 2, "GAME OVER");
    drawString(30, 4, "SCORE: "); drawInt(70, 4, score);
    
    playCustomSong(gameOverMelody, gameOverTempo, 4);
    delay(1000);
    drawString(20, 6, "PRESS FIRE");
    
    while(!readFire()) { /* Wait */ }
    delay(300); gameState = 1; 
  }
}

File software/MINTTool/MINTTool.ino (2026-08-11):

/*
 * =========================================================================================
 * TINY ARC BUDDY - EDUCATIONAL EMBEDDED PLATFORM
 * =========================================================================================
 * * Copyright (c) 2026 Andreas Kucher
 * * Permission is hereby granted, free of charge, to any person obtaining a copy
 * of this software and associated documentation files (the "Software"), to deal
 * in the Software without restriction, including without limitation the rights
 * to use, copy, modify, merge, publish, distribute, sublicense, and/or sell
 * copies of the Software, and to permit persons to whom the Software is
 * furnished to do so, subject to the following conditions:
 * * The above copyright notice and this permission notice shall be included in all
 * copies or substantial portions of the Software.
 * * THE SOFTWARE IS PROVIDED "AS IS", WITHOUT WARRANTY OF ANY KIND, EXPRESS OR
 * IMPLIED, INCLUDING BUT NOT LIMITED TO THE WARRANTIES OF MERCHANTABILITY,
 * FITNESS FOR A PARTICULAR PURPOSE AND NONINFRINGEMENT. IN NO EVENT SHALL THE
 * AUTHORS OR COPYRIGHT HOLDERS BE LIABLE FOR ANY CLAIM, DAMAGES OR OTHER
 * LIABILITY, WHETHER IN AN ACTION OF CONTRACT, TORT OR OTHERWISE, ARISING FROM,
 * OUT OF OR IN CONNECTION WITH THE SOFTWARE OR THE USE OR OTHER DEALINGS IN THE
 * SOFTWARE.
 * * -----------------------------------------------------------------------------------------
 * ACKNOWLEDGMENTS & DISCLAIMER
 * -----------------------------------------------------------------------------------------
 * This project was designed for STEM education workshops.
 * * Core hardware architecture derived from:
 * "Tiny Arcade Game (ATtiny85)" - Instructables
 * * Hardware support via:
 * ATTinyCore by Spence Konde (https://github.com/SpenceKonde/ATTinyCore)
 * * Disclaimer: The software payloads in this repository were heavily optimized 
 * for ATtiny85 SRAM/Flash constraints with the assistance of AI (Google Gemini). 
 * They have not undergone exhaustive edge-case testing. Use for educational purposes.
 * =========================================================================================
 */

/*
 * ==============================================================================
 * TINY ARC BUDDY - GENIUS EDITION (Flicker-Free, Live Equations)
 * ==============================================================================
 */

#include <avr/io.h>
#include <util/delay.h>

#include "font.h"     
#include "graphics.h" 
#include "formulas.h"

// ==============================================================================
// ZONE 1: APP SETTINGS
// ==============================================================================
#define OWNER_NAME "ANNA"           
#define BUILD_DATE "25.04.2026"      

#define OLED_SDA PB3  
#define OLED_SCL PB4  
#define BTN_LEFT PB0  
#define BTN_RIGHT PB2 
#define BUZZER PB1    

byte appState = 0; 
bool needsRedraw = true; // Our flicker-prevention flag!

int activeCat = 0;
int activeTool = 0;
int activeUnitGroup = 0;
int selectedUnitIdx = 0;

int inputVals[6];     
int currentInput = 0; 
int inputStep = 0;    

unsigned long lastMoveTime = 0;
bool leftWasPressed = false;
bool rightWasPressed = false;
bool fireWasPressed = false;

// ------------------------------------------------------------------------------
// I2C BIT-BANGING & GRAPHICS ENGINE
// ------------------------------------------------------------------------------
inline void i2c_start() {
  PORTB |= (1 << OLED_SDA) | (1 << OLED_SCL);
  PORTB &= ~(1 << OLED_SDA); PORTB &= ~(1 << OLED_SCL);
}
inline void i2c_stop() {
  PORTB &= ~(1 << OLED_SDA); PORTB |= (1 << OLED_SCL) | (1 << OLED_SDA);
}
void i2c_write(uint8_t data) {
  for (uint8_t i = 0; i < 8; i++) {
    if (data & 0x80) PORTB |= (1 << OLED_SDA); else PORTB &= ~(1 << OLED_SDA);
    PORTB |= (1 << OLED_SCL); PORTB &= ~(1 << OLED_SCL);
    data <<= 1;
  }
  PORTB |= (1 << OLED_SCL); PORTB &= ~(1 << OLED_SCL);
}
void oled_command(uint8_t cmd) {
  i2c_start(); i2c_write(0x78); i2c_write(0x00); i2c_write(cmd); i2c_stop();
}
void oled_set_cursor(uint8_t x, uint8_t y) {
  oled_command(0xB0 + y);                 
  oled_command(0x00 + (x & 0x0F));        
  oled_command(0x10 + ((x >> 4) & 0x0F)); 
}
void oled_clear() {
  for (uint8_t y = 0; y < 8; y++) {
    oled_set_cursor(0, y);
    i2c_start(); i2c_write(0x78); i2c_write(0x40);
    for (uint8_t x = 0; x < 128; x++) i2c_write(0x00);
    i2c_stop();
  }
}

void drawChar(uint8_t x, uint8_t page, char c) {
  uint8_t idx = 0; bool isSpace = false;
  if (c >= '0' && c <= '9') idx = c - '0' + 1;
  else if (c >= 'a' && c <= 'z') idx = (c - 32) - 'A' + 11; 
  else if (c >= 'A' && c <= 'Z') idx = c - 'A' + 11;
  else if (c == '\'') idx = 37; else if (c == '@') idx = 38;
  else if (c == ':') idx = 39; else if (c == '.') idx = 40;
  else if (c == '-') idx = 41; else if (c == '=') idx = 42;
  else if (c == '(' || c == '[') idx = 43; 
  else if (c == ')' || c == ']') idx = 44;
  else if (c == '^') idx = 45; else if (c == '%') idx = 46;
  else if (c == '+') idx = 47; else if (c == '*') idx = 48;
  else if (c == '/') idx = 49; else if (c == ',') idx = 50;
  else if (c == '_') idx = 51; else if (c == ' ') { isSpace = true; }
  
  oled_set_cursor(x, page);
  i2c_start(); i2c_write(0x78); i2c_write(0x40);
  
  if (isSpace || idx == 0) for(uint8_t i=0; i<6; i++) i2c_write(0x00);
  else {
    for(uint8_t i=0; i<5; i++) i2c_write(pgm_read_byte(&font5x7[idx * 5 + i]));
    i2c_write(0x00); 
  }
  i2c_stop();
}

void drawString(uint8_t x, uint8_t page, const char* str) {
  while (*str) { drawChar(x, page, *str++); x += 6; }
}

void drawStringPGM(uint8_t x, uint8_t page, const char* pgmStr) {
  char c;
  while ((c = pgm_read_byte(pgmStr++)) != 0) { drawChar(x, page, c); x += 6; }
}

// THE FLICKER KILLER: Erases leftover pixels on a line instantly!
void clearRestOfLine(uint8_t x, uint8_t page) {
  while (x < 124) { drawChar(x, page, ' '); x += 6; }
}

// Live-updating Equation Element (e.g., "[ 12]x" or "  5 y")
void drawEqElem(uint8_t &x, uint8_t page, int val, bool isActive, char varName) {
  if (isActive) { drawChar(x, page, '['); x+=6; }
  else { drawChar(x, page, ' '); x+=6; } // Spaces align perfectly!

  char buf[8]; itoa(val, buf, 10);
  drawString(x, page, buf); x+= strlen(buf)*6;

  if (isActive) { drawChar(x, page, ']'); x+=6; }
  else { drawChar(x, page, ' '); x+=6; }

  if (varName != ' ') { drawChar(x, page, varName); x+=6; }
}

void drawFixedPoint(uint8_t x, uint8_t page, long val) {
  if (val < 0) { drawChar(x, page, '-'); x += 6; val = -val; }
  long whole = val / 100;
  int frac = val % 100;
  
  char buf[12]; itoa(whole, buf, 10);
  int len = strlen(buf);
  buf[len] = '.'; buf[len+1] = (frac / 10) + '0';
  buf[len+2] = (frac % 10) + '0'; buf[len+3] = '\0';
  drawString(x, page, buf);
}
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
